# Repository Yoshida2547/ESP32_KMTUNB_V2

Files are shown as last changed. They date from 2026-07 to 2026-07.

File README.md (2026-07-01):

# ESP32KMUTNB_V2.0

A comprehensive ESP32-based embedded system design featuring multiple sensors, display interfaces, and USB connectivity for IoT and wearable applications.

## Overview

This project is a hardware design for an ESP32 microcontroller-based system that integrates:
- **Microcontroller**: ESP32 with USB-to-UART bridge
- **Sensors**: ADXL345 accelerometer, MAX30102 heart rate sensor, LPS22H barometric pressure sensor, HDC1080 humidity/temperature sensor
- **Display Interfaces**: TFT LCD display (3.5" 480×320 SPI) and I²C LCD module
- **Connectivity**: USB Type-C for programming and power, I²C and SPI communication buses
- **I/O**: Push buttons, RGB LED, buzzer, and GPIO headers

## Project Structure

```
ESP32KMUTNB_V2.0/
├── ESP32KMUTNB_V2.0.kicad_pro          # KiCad project file
├── ESP32KMUTNB_V2.0.kicad_sch          # Main schematic
├── ESP32KMUTNB_V2.0.kicad_pcb          # PCB layout
├── Microcontroller.kicad_sch           # Microcontroller subsystem
├── Sensor.kicad_sch                    # Sensor subsystem
├── TFT_Display.kicad_sch               # TFT display connections
├── LCD_Display.kicad_sch               # LCD display connections
├── Header.kicad_sch                    # GPIO header configuration
├── USB-to-UART Bridge.kicad_sch        # USB communication module
├── Bottons.kicad_sch                   # Button configuration
├── hardware_libs/                      # Custom libraries
│   ├── ADXL345BCCZ-RL.kicad_sym       # ADXL345 symbol
│   ├── MAX30102_Module.kicad_sym      # MAX30102 symbol
│   ├── TFT_LCD_Display.kicad_sym      # Display symbol
│   ├── footprints.pretty/             # Custom footprints
│   └── 3d_model/                      # 3D models for components
└── fp-lib-table                        # Footprint library table
```

## Key Components

| Component | Part Number | Function |
|---|---|---|
| Microcontroller | ESP32-S3 | Main processing unit |
| USB Bridge | CH340/CH341 | USB-to-UART conversion |
| Accelerometer | ADXL345BCCZ-RL | 3-axis acceleration sensing |
| Heart Rate Sensor | MAX30102 | PPG heart rate and SpO₂ measurement |
| Pressure Sensor | LPS22H | Barometric pressure and altitude |
| Humidity/Temp | HDC1080 | Temperature and humidity measurement |
| Display | ILI9488 | 3.5" TFT LCD interface |
| LED Indicators | WS2812B | RGB addressable LED |

## Schematic Organization

The design is organized into functional subsystems:

1. **Microcontroller** - ESP32 core with reset, boot circuitry, and power management
2. **USB Bridge** - CH340 UART-to-USB converter with ESD protection
3. **Sensors** - I²C sensor array with pull-up resistors and decoupling capacitors
4. **Display** - SPI TFT display interface with control signals
5. **Headers** - GPIO breakout connectors for expansion
6. **Power** - +5V input, +3.3V regulation with decoupling

## Pin Configuration

### I²C Sensors (I2C0/I2C1)
- SENSOR_SDA / SENSOR_SCL
- Connected to: ADXL345, MAX30102, LPS22H, HDC1080

### SPI Displays
- TFT LCD uses standard SPI interface
- CLK, MOSI, CS, DC, RESET signals

### GPIO Headers (J5)
- 32-pin connector with labeled I/O signals
- Supports additional peripherals and debugging

## Manufacturing Notes

- **PCB Layers**: 4-layer board
- **Design Date**: May 30, 2026
- **Revision**: A
- **3D Models**: Available for ADXL345 and MSP3520 components

## Design Files

- **KiCad Version**: 8.0.3 or later
- **Library Dependencies**: Custom symbols and footprints included
- **DXF Files**: MAX30102 module reference drawing included

## Usage

1. Open `ESP32KMUTNB_V2.0.kicad_pro` in KiCad
2. Review subsystem schematics for specific circuit details
3. Edit PCB layout in `ESP32KMUTNB_V2.0.kicad_pcb`
4. Generate production files (Gerbers, drill files) as needed

## Documentation

Refer to the individual schematic sheets for detailed circuit descriptions:
- Microcontroller configuration and boot circuitry
- Sensor connectivity and addressing
- Display interface pinout
- Power distribution and grounding strategy

## Author

Design by Surasak M. (Mark)
KMTUNB

## License

[Specify your license here]

## Contact

For questions or modifications, please contact the design team.

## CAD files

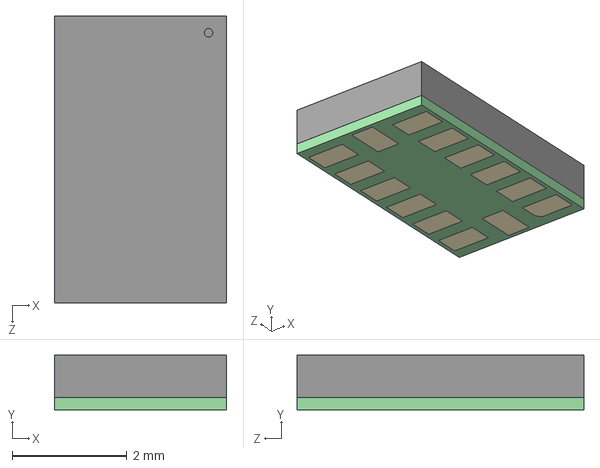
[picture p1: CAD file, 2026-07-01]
ADXL345BCCZ-RL.stp
3.00 x 0.95 x 5.00 mm

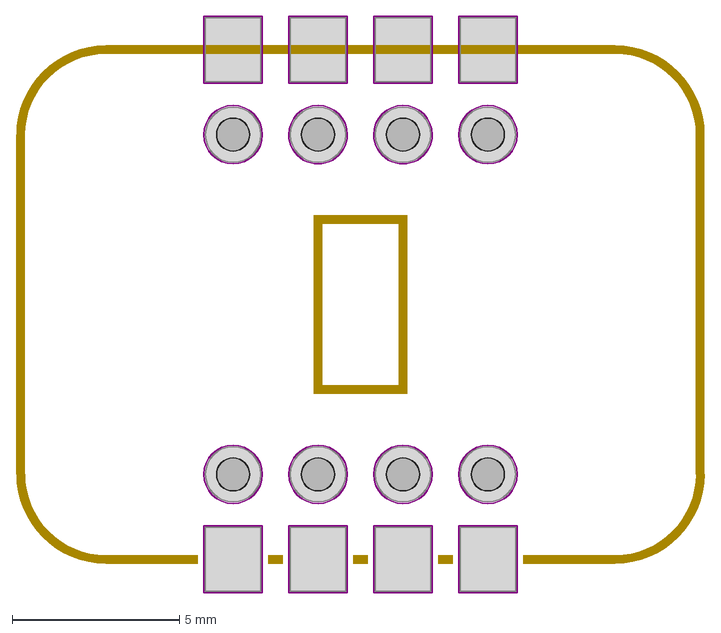
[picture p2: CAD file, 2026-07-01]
DXF_MAX30102_2026-07-01_AutoCAD2007.dxf
20.6 x 17.2 mm

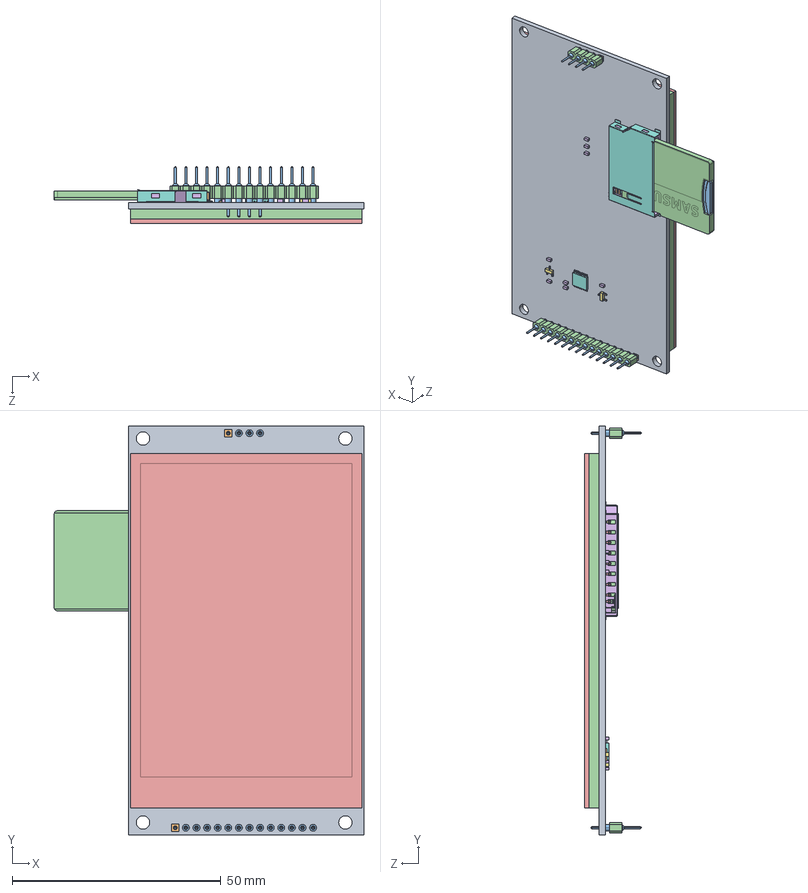
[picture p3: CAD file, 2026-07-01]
hardware_libs/3d_model/MSP3520.STEP
74.2 x 98.0 x 13.6 mm
TFT SPI Serial LCD Module 480X320 Driver IC ILI9488_XPT2046_MSP3520
card sd_Valor predeterminado
microSDCard
contact01.step
contact02.step
contact03.step
contact04.step
contact05.step
contact06.step
contact07.step
contact08.step
frame.step
contact09.step
cover.step
contact11.step
contact10.step
Штыревой разъем 14 конт шаг 2.54мм
Штыревой разъем 4 конт шаг 2.54мм

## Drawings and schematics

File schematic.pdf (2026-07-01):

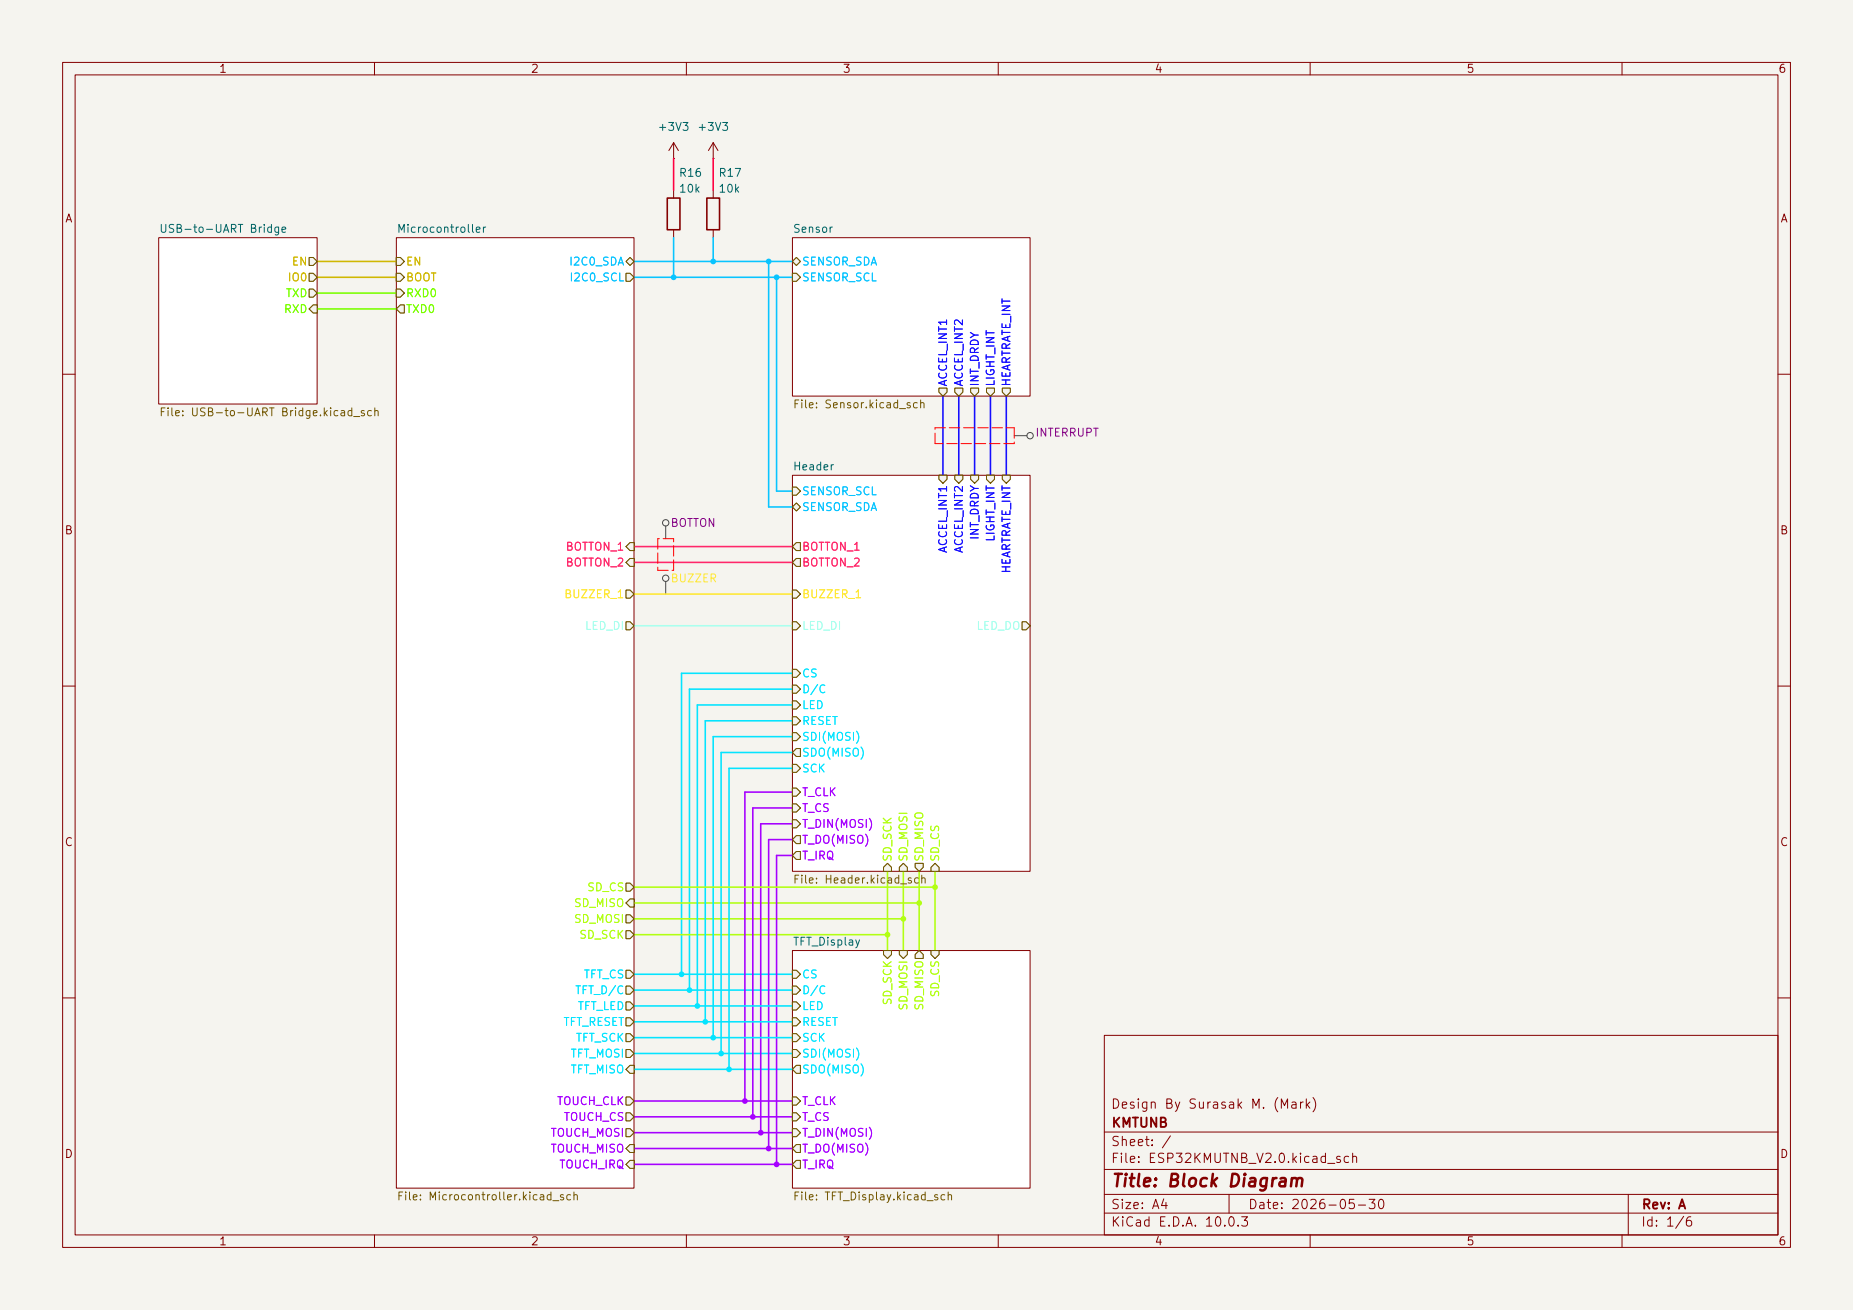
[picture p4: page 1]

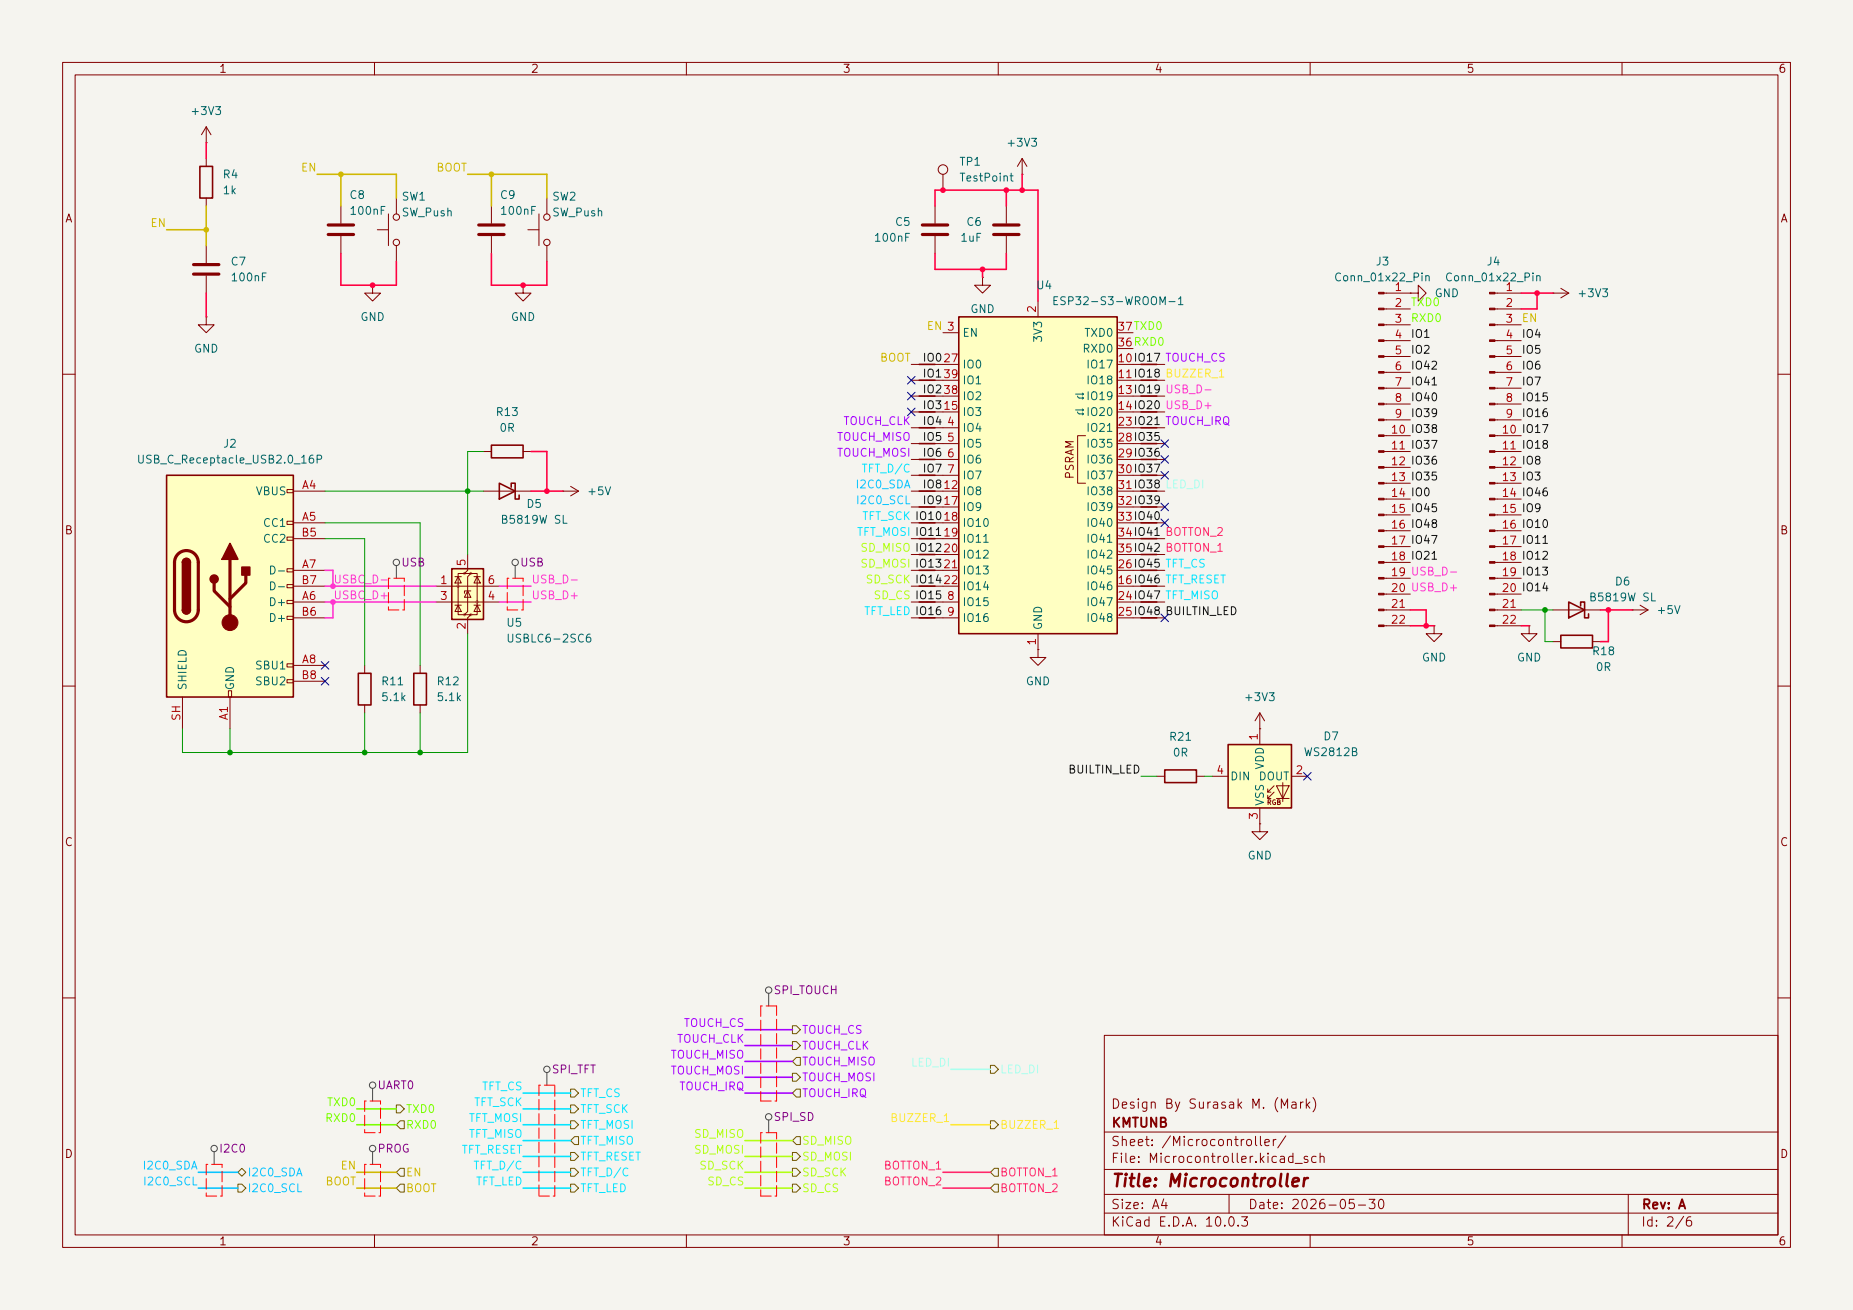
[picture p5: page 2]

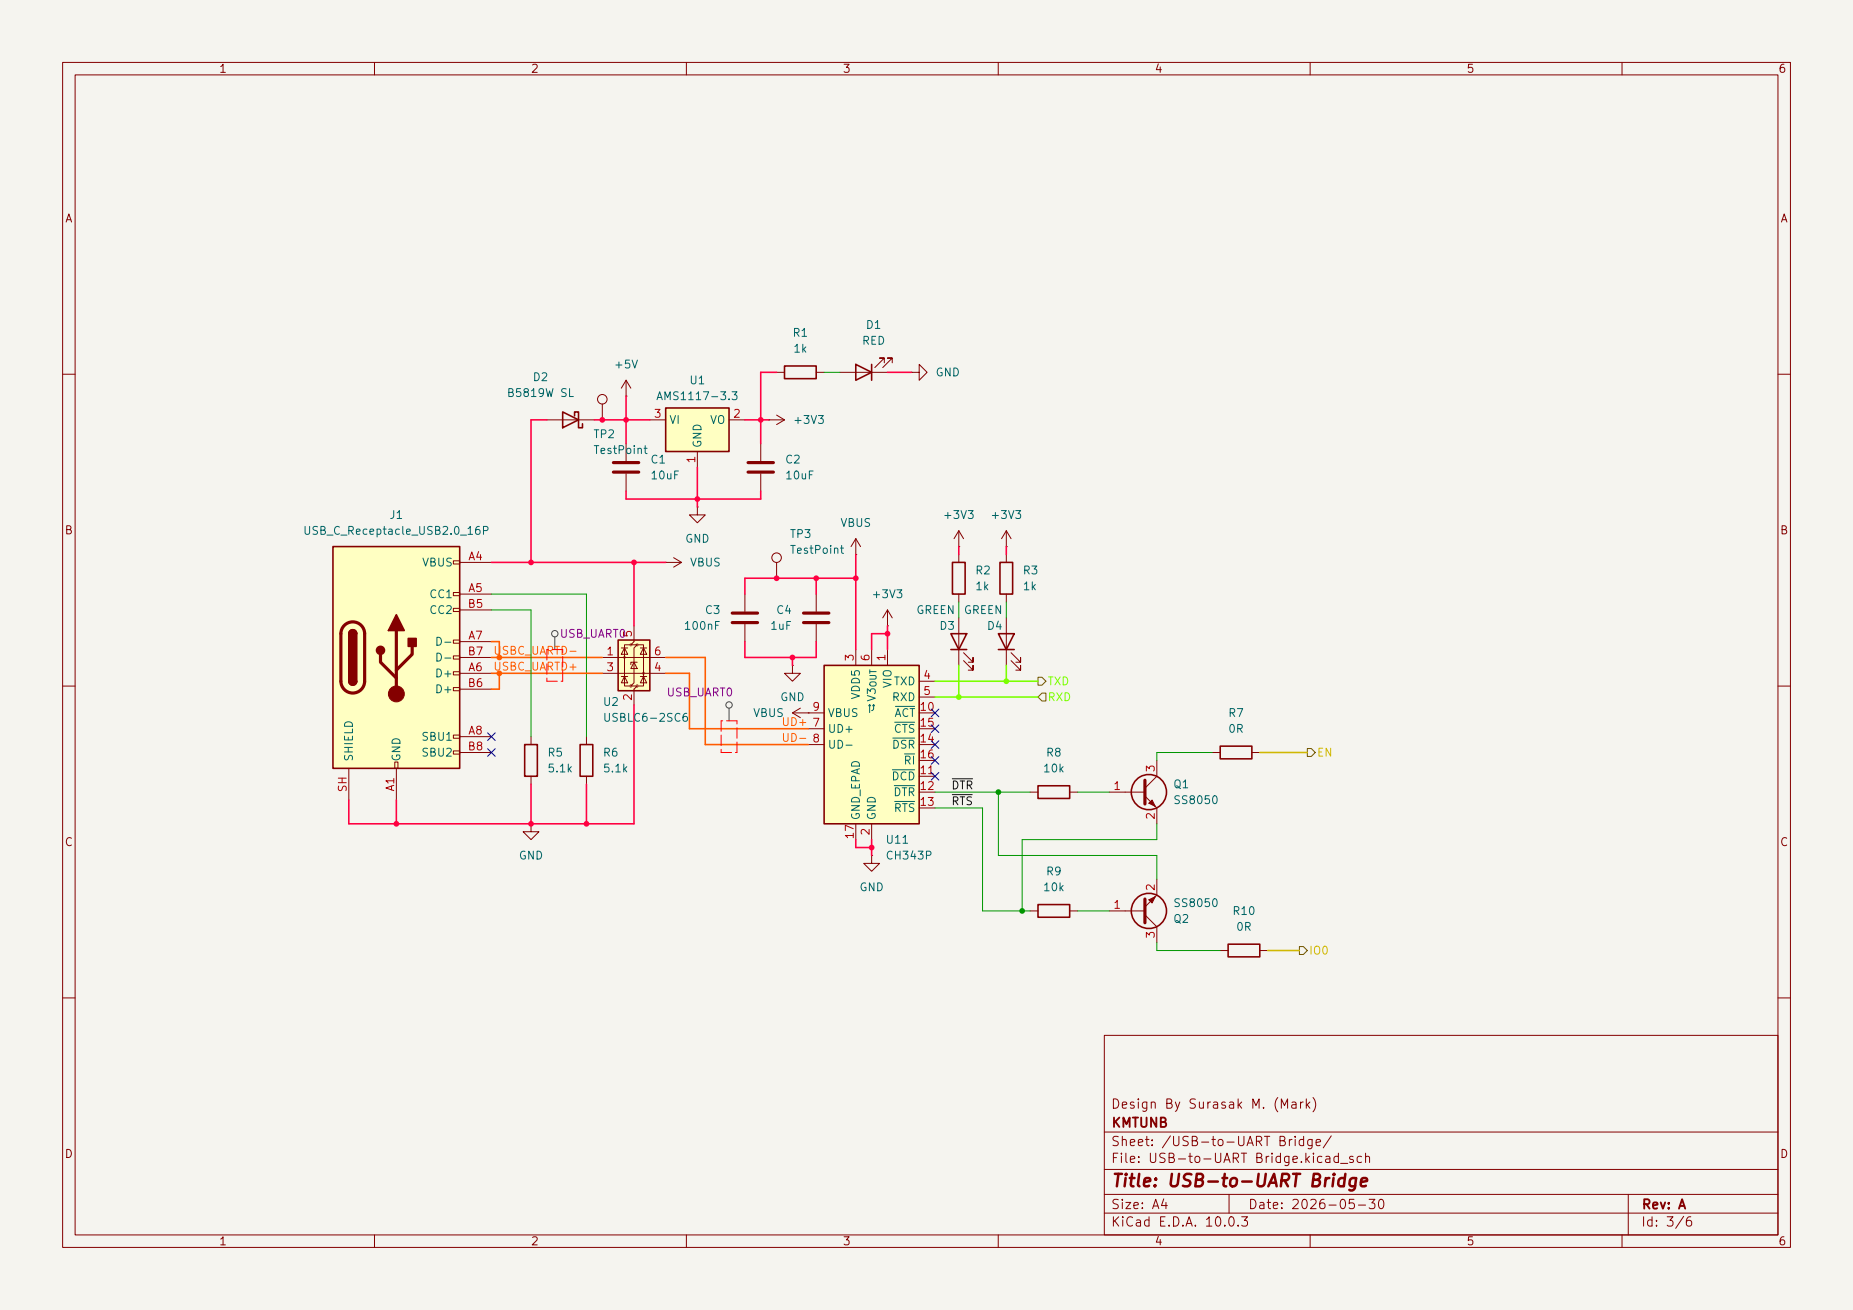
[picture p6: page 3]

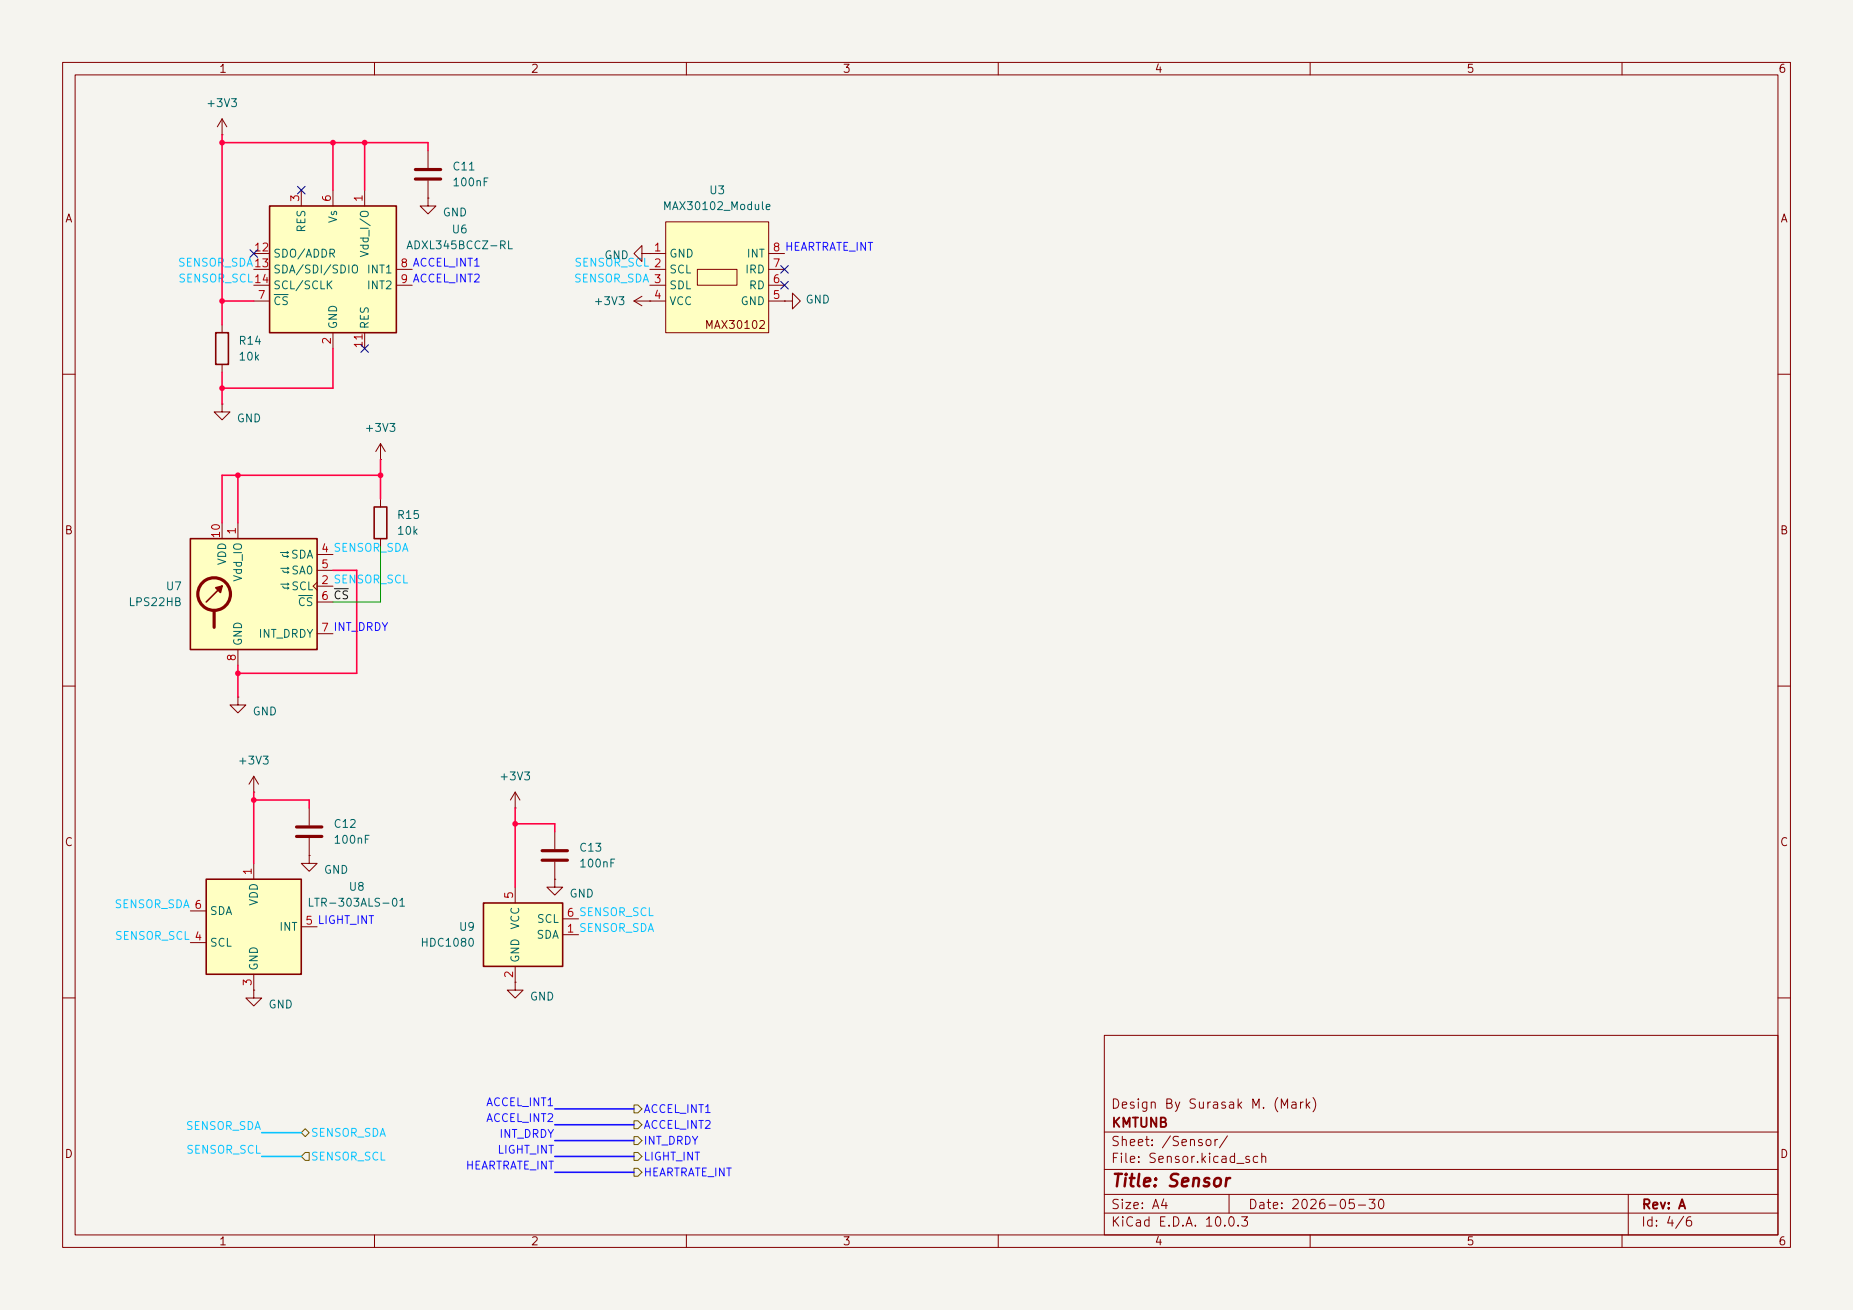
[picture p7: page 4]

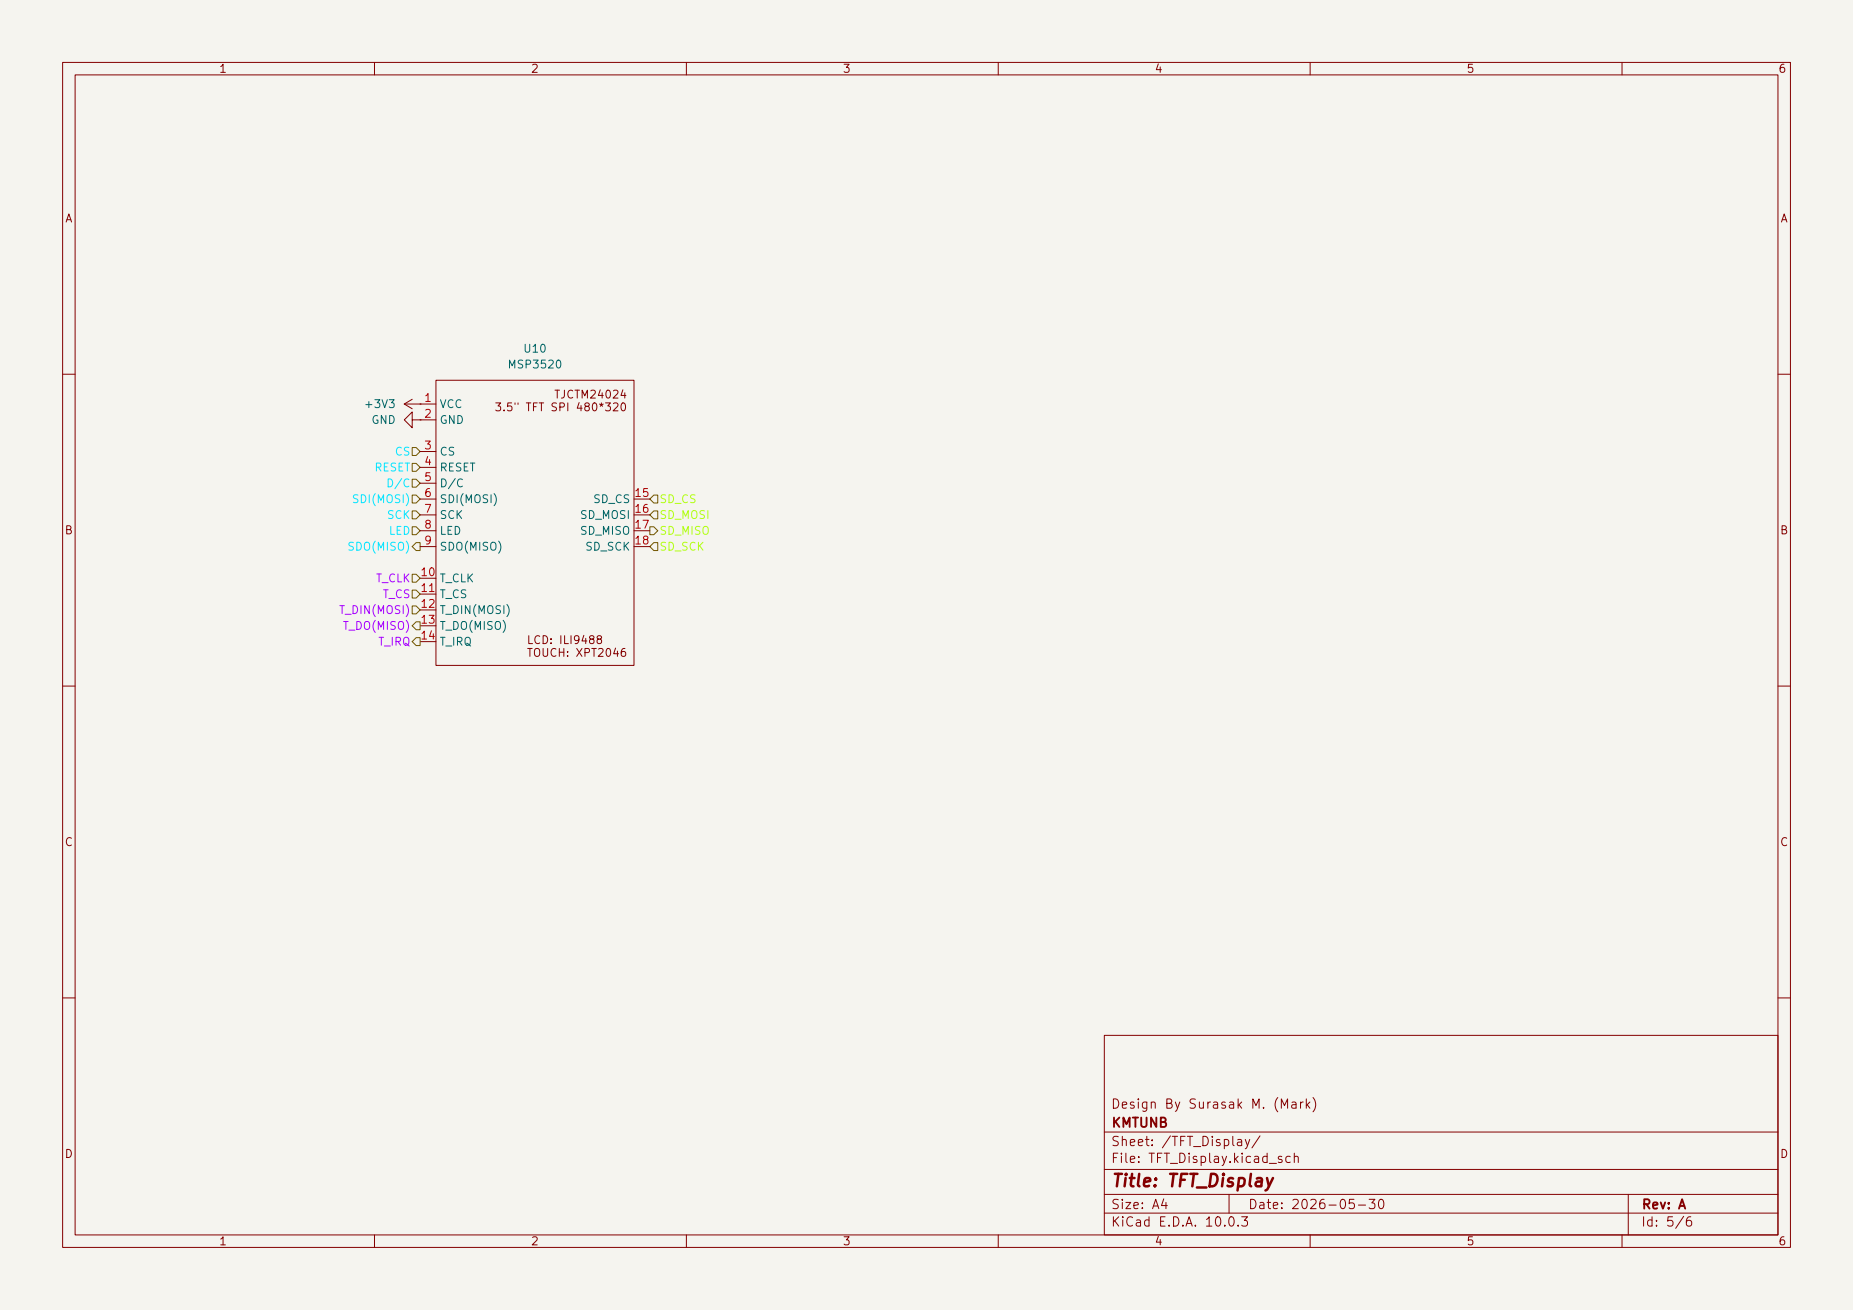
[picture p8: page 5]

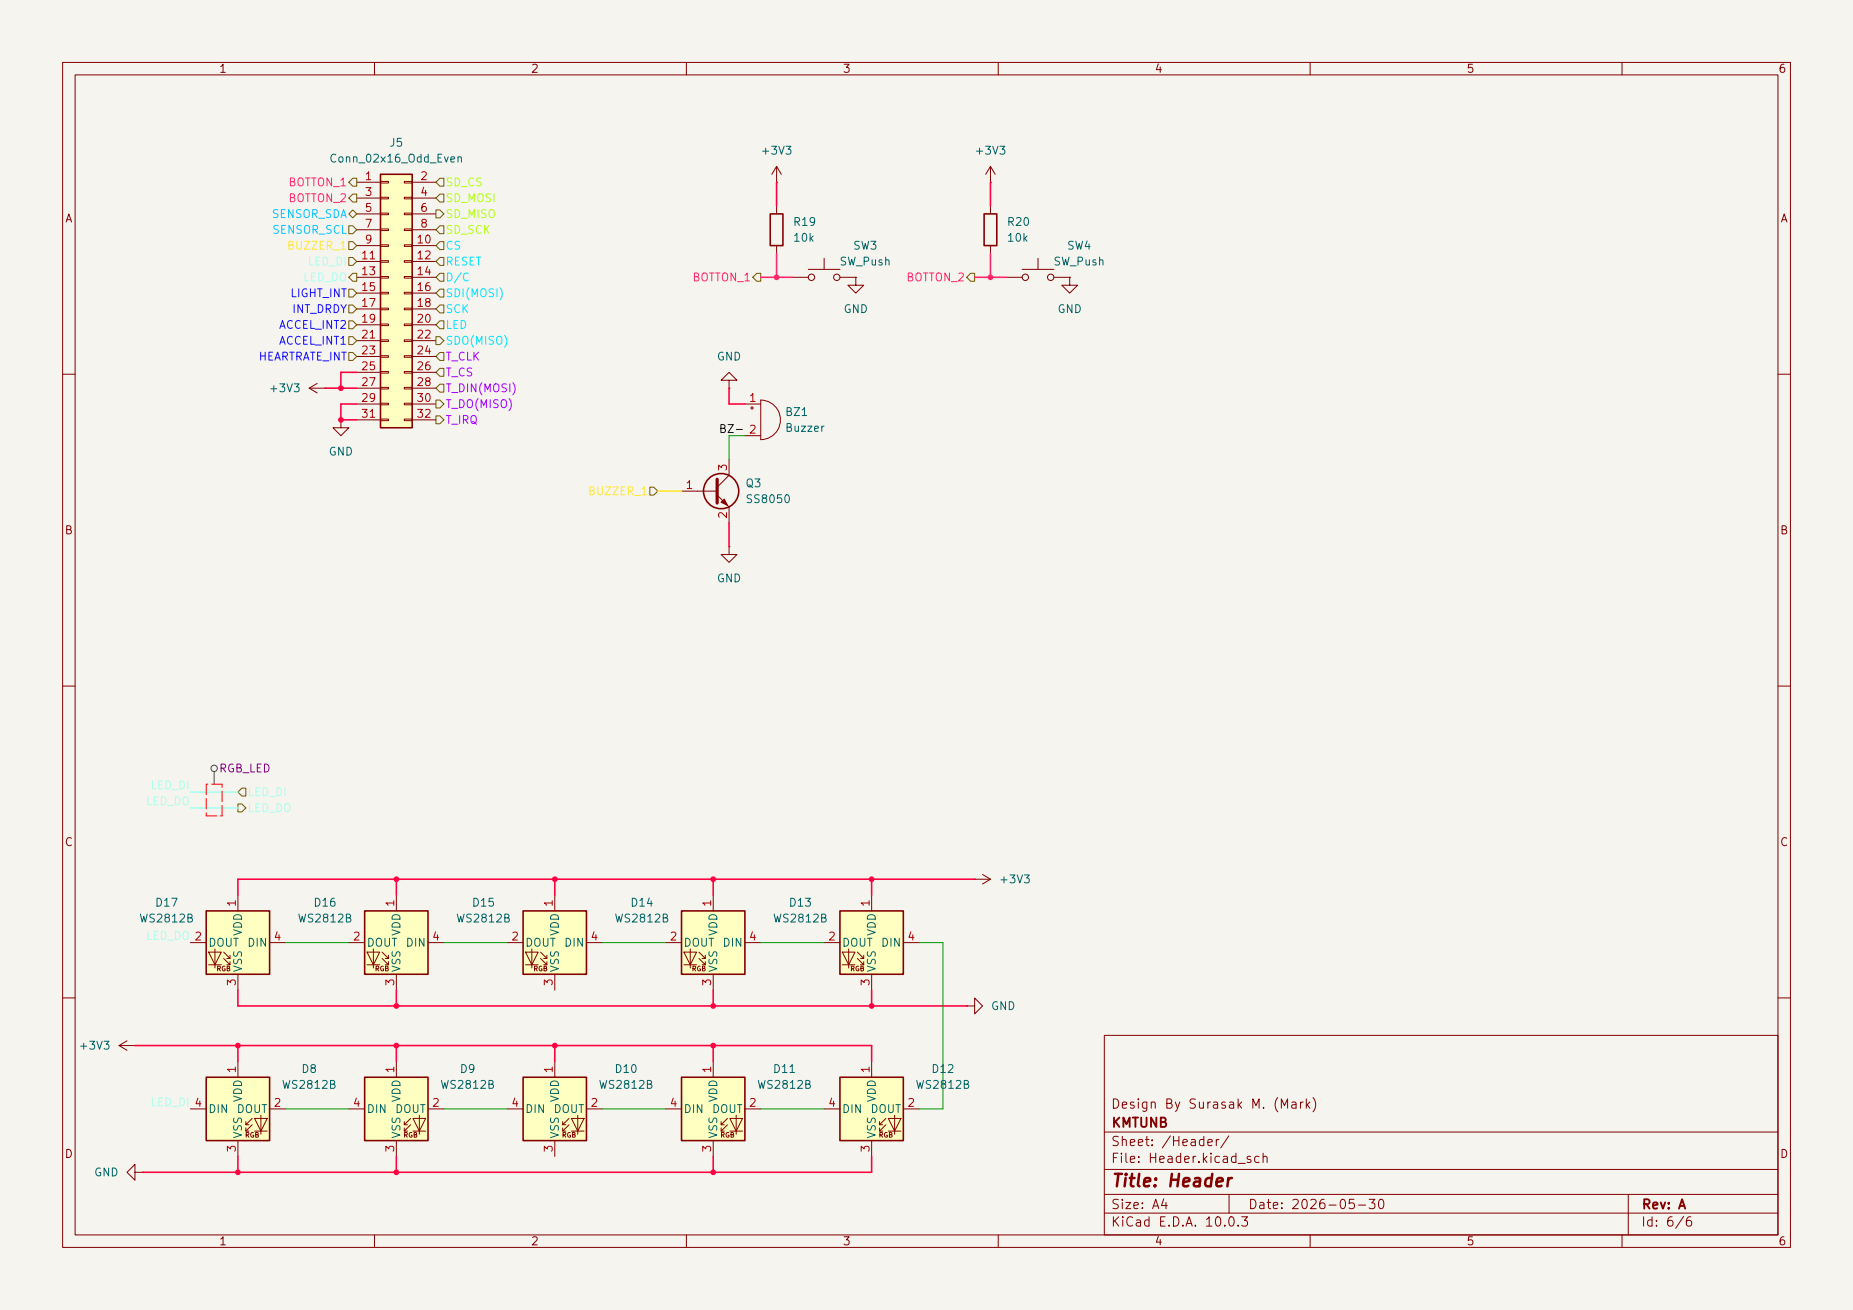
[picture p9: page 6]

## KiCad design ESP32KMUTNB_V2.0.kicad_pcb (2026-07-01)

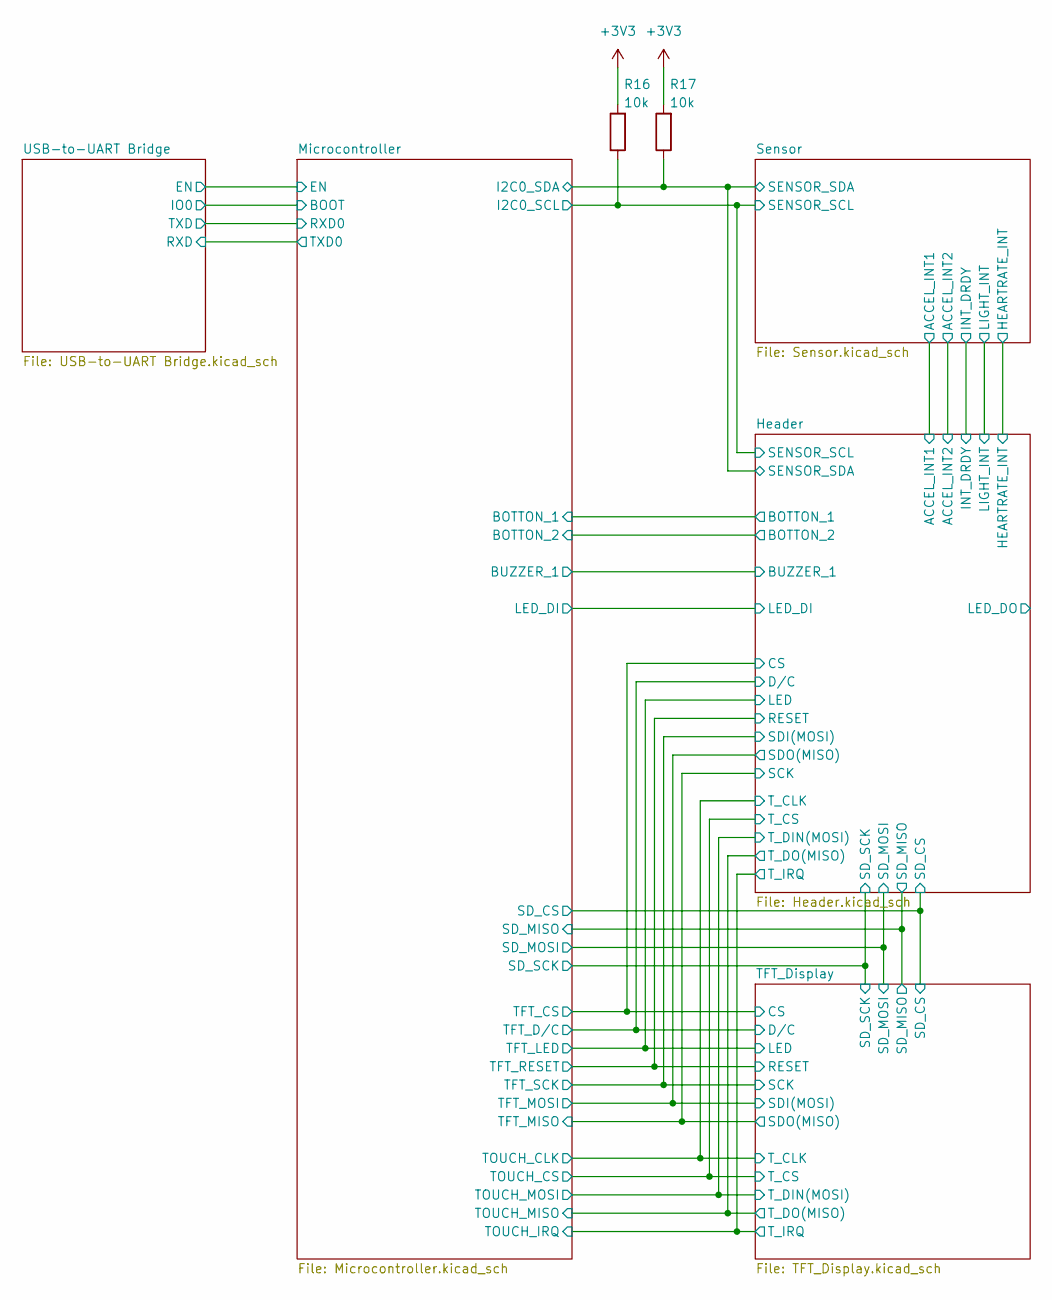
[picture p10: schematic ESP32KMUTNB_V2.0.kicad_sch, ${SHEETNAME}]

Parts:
R16, R17: 10k; R_0603_1608Metric_Pad0.98x0.95mm_HandSolder; MPN 0603WAF1002T5E

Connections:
+3V3: R16.2, R17.2; also elsewhere on the board
/Microcontroller/I2C0_SCL: R16.1; also elsewhere on the board
/Microcontroller/I2C0_SDA: R17.1; also elsewhere on the board

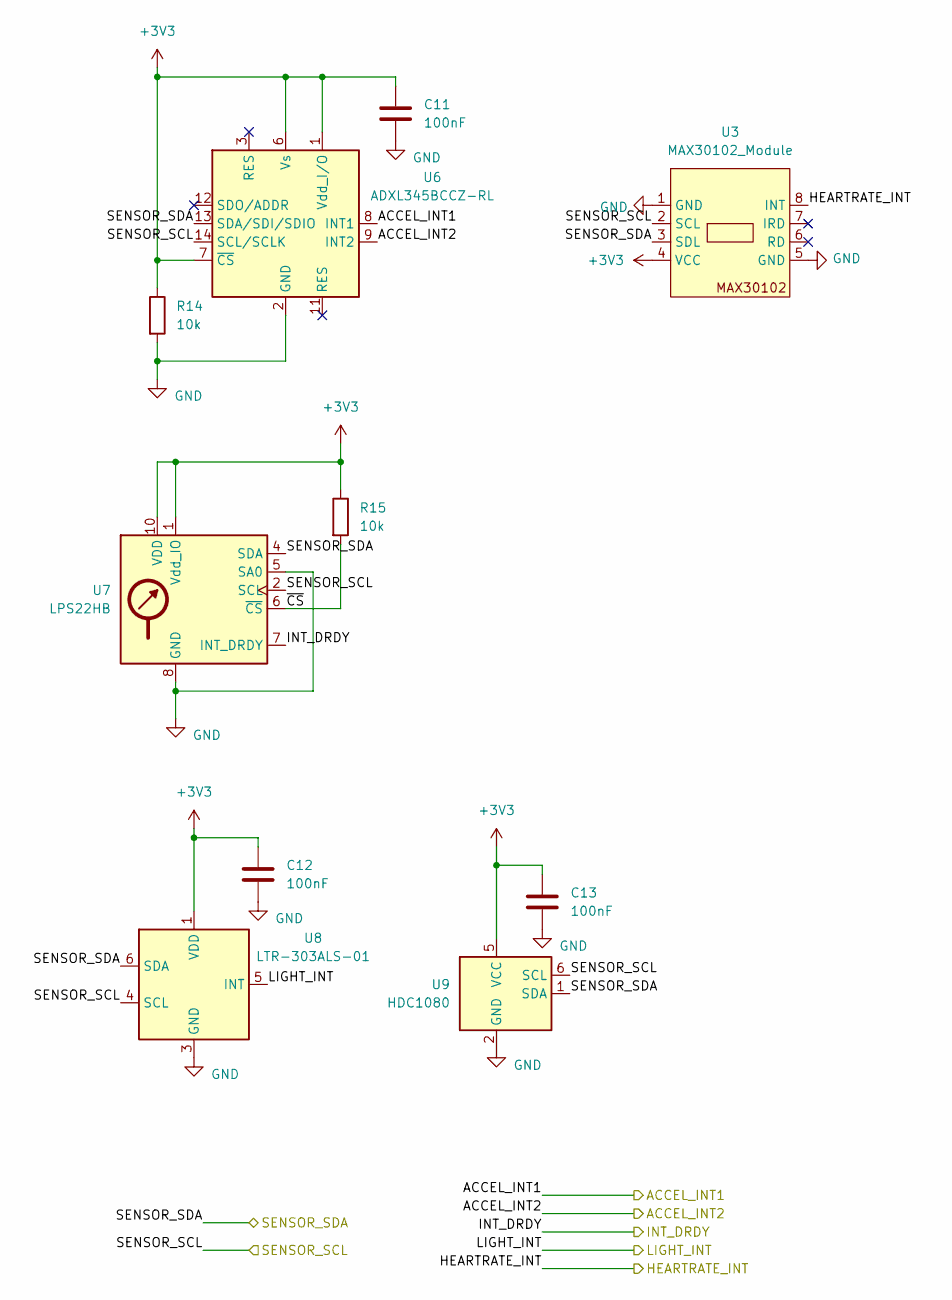
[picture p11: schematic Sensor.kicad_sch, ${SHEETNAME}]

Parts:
C11, C12, C13: 100nF; C_0402_1005Metric_Pad0.74x0.62mm_HandSolder; MPN CL05B104KO5NNNC
R14, R15: 10k; R_0603_1608Metric_Pad0.98x0.95mm_HandSolder; MPN 0603WAF1002T5E
U3: MAX30102_Module; MAX30102
U6: ADXL345BCCZ-RL; LGA-14_3x5mm_P0.8mm_LayoutBorder1x6y; MPN ADXL345BCCZ-RL
U7: LPS22HB; ST_HLGA-10_2x2mm_P0.5mm_LayoutBorder3x2y; MPN LPS22HBTR
U8: LTR-303ALS-01; Lite-On_LTR-303ALS-01; MPN LTR-303ALS-01
U9: HDC1080; Texas_PWSON-N6; MPN HDC1080DMBR

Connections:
+3V3: C11.1, C12.1, C13.1, R14.1, R15.1, U3.4 (VCC), U6.1 (Vdd_I/O), U6.6 (Vs), U6.7 (~CS), U7.1 (Vdd_IO), U7.10 (VDD), U8.1 (VDD), U9.5 (VCC); also elsewhere on the board
/Microcontroller/I2C0_SCL: U3.2 (SCL), U6.14 (SCL/SCLK), U7.2 (SCL), U8.4 (SCL), U9.6 (SCL); also elsewhere on the board
/Microcontroller/I2C0_SDA: U3.3 (SDL), U6.13 (SDA/SDI/SDIO), U7.4 (SDA), U8.6 (SDA), U9.1 (SDA); also elsewhere on the board
/Sensor/ACCEL_INT1: U6.8 (INT1); also elsewhere on the board
/Sensor/ACCEL_INT2: U6.9 (INT2); also elsewhere on the board
/Sensor/HEARTRATE_INT: U3.8 (INT); also elsewhere on the board
/Sensor/INT_DRDY: U7.7 (INT_DRDY); also elsewhere on the board
/Sensor/LIGHT_INT: U8.5 (INT); also elsewhere on the board
/Sensor/~CS: R15.2, U7.6 (~CS)
GND: C11.2, C12.2, C13.2, R14.2, U3.1 (GND), U3.5 (GND), U6.2 (GND), U6.4 (GND), U6.5 (GND), U7.3 (GND), U7.5 (SA0), U7.8 (GND), U7.9 (GND), U8.3 (GND), U9.2 (GND); also elsewhere on the board

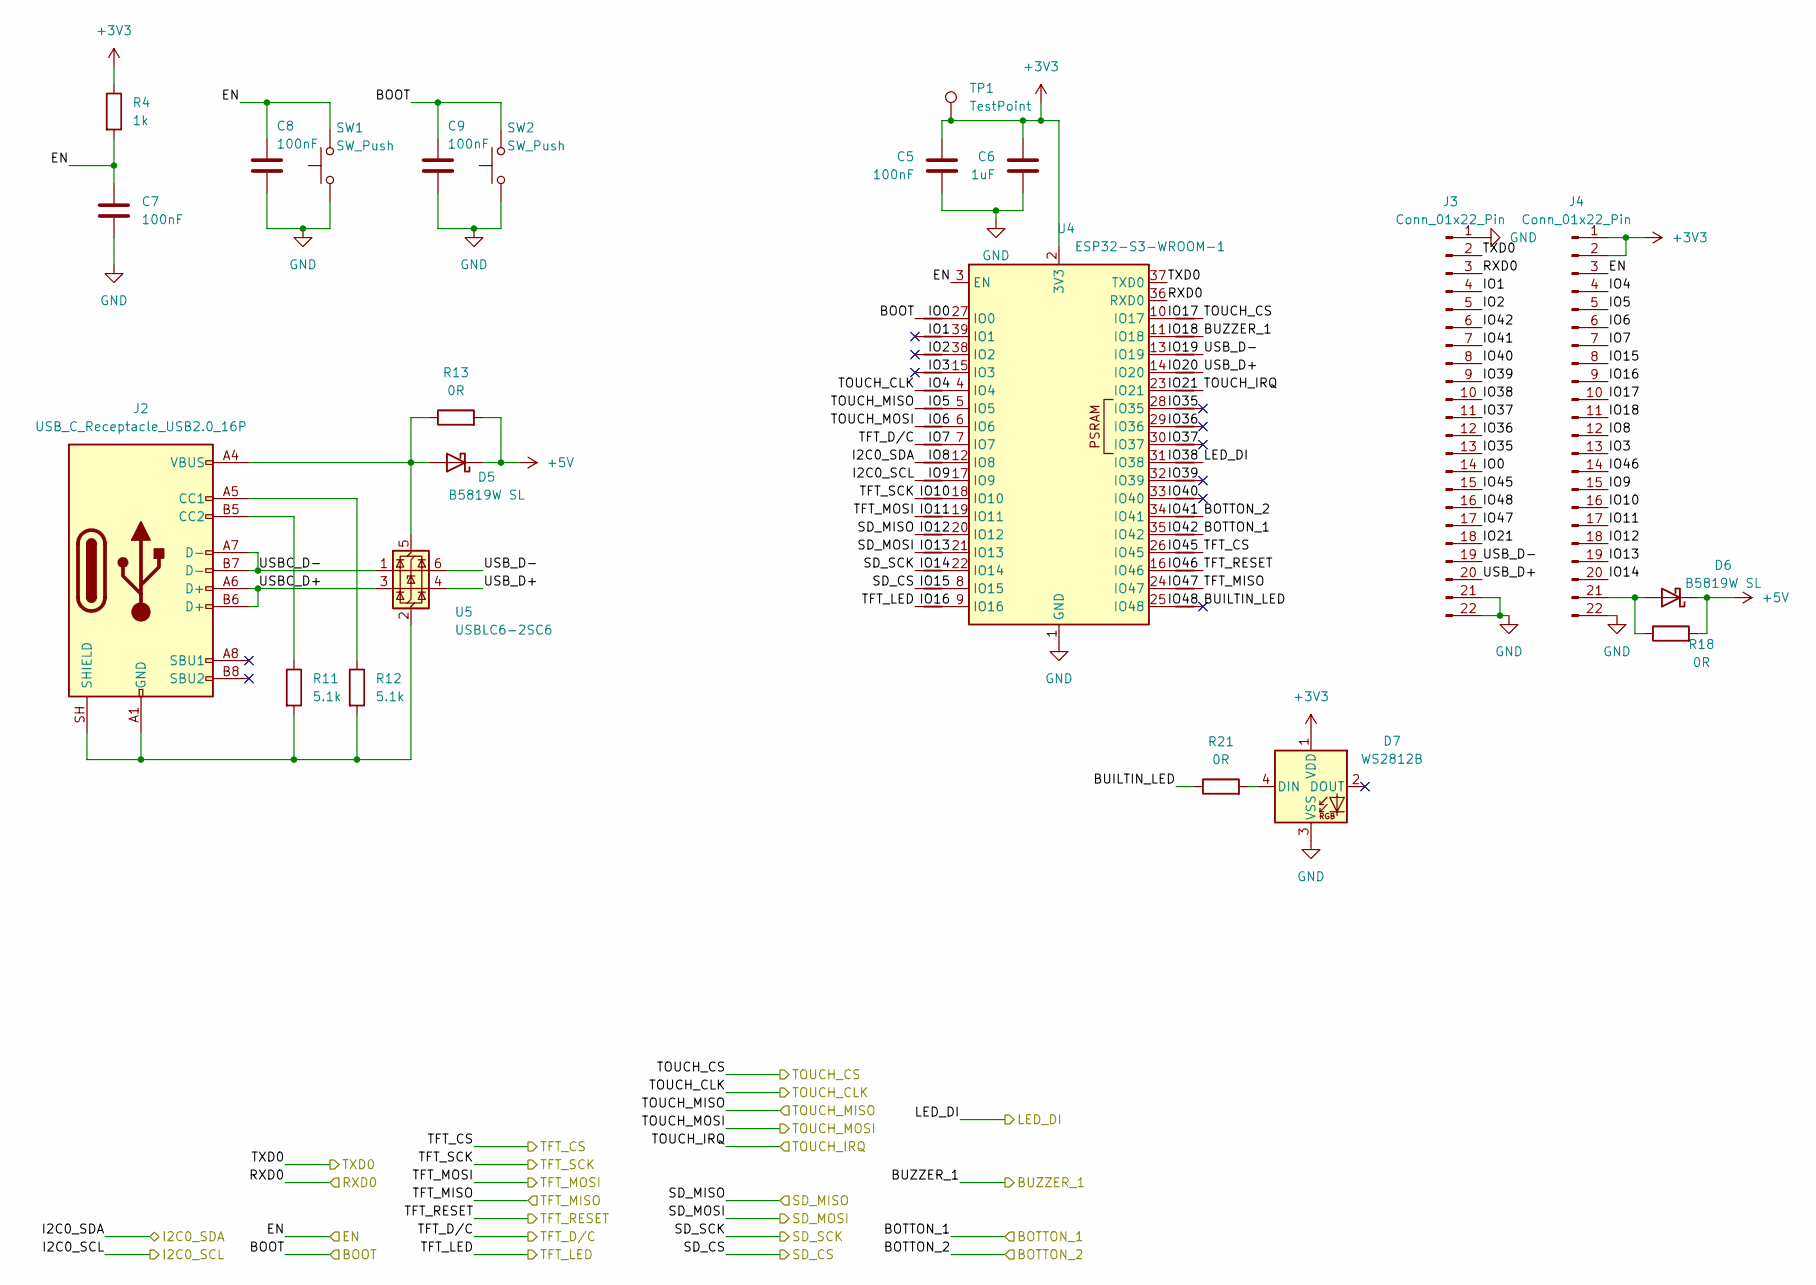
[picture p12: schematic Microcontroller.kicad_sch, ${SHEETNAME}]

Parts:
C5, C7, C8, C9: 100nF; C_0402_1005Metric_Pad0.74x0.62mm_HandSolder; MPN CL05B104KO5NNNC
C6: 1uF; C_0603_1608Metric_Pad1.08x0.95mm_HandSolder; MPN CL10A105KB8NNNC
D5, D6: B5819W SL; D_SOD-123; MPN B5819W SL
D7: WS2812B; LED_WS2812B_PLCC4_5.0x5.0mm_P3.2mm
J2: USB_C_Receptacle_USB2.0_16P; USB_C_Receptacle_G-Switch_GT-USB-7010ASV; MPN G-Switch GT-USB-7010ASV
J3, J4: Conn_01x22_Pin; PinSocket_1x22_P2.54mm_Vertical
NT1, NT2, NT3, NT4, NT5, NT6, NT7, NT8, NT9, NT10, NT11, NT12, NT13, NT14, NT15, NT16, NT17, NT18, NT19, NT20, NT21, NT22, NT23, NT24, NT25, NT26, NT27, NT28, NT29, NT30, NT31, NT32, NT33, NT34: NetTie_2; NetTie-2_SMD_Pad0.5mm
R4: 1k; R_0603_1608Metric_Pad0.98x0.95mm_HandSolder; MPN 0603WAF1001T5E
R11, R12: 5.1k; R_0603_1608Metric_Pad0.98x0.95mm_HandSolder; MPN 0603WAF5101T5E
R13, R18, R21: 0R; R_0603_1608Metric_Pad0.98x0.95mm_HandSolder; MPN 0603WAF0000T5E
SW1, SW2: SW_Push; SW_SPST_B3U-1000P; MPN XUNPU TS-1088-AR02016
TP1: TestPoint; TestPoint_Pad_D1.5mm
U4: ESP32-S3-WROOM-1; MPN ESP32-S3-WROOM-1-N8R2
U5: USBLC6-2SC6; SOT-23-6; MPN USBLC6-2SC6

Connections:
+3V3: C5.1, C6.1, D7.1 (VDD), J4.1, J4.2, R4.1, TP1.1 (1_1), U4.2 (3V3); also elsewhere on the board
+5V: D5.1 (K), D6.1 (K), R13.2, R18.2; also elsewhere on the board
/Header/LED_DI: NT22.2; also elsewhere on the board
/Microcontroller/BOOT: C9.1, NT14.1, SW2.2; also elsewhere on the board
/Microcontroller/BOTTON_1: NT27.2; also elsewhere on the board
/Microcontroller/BOTTON_2: NT25.2; also elsewhere on the board
/Microcontroller/BUILTIN_LED: NT32.2, R21.1
/Microcontroller/BUZZER_1: NT28.2; also elsewhere on the board
/Microcontroller/EN: C7.1, C8.1, J4.3, R4.2, SW1.2, U4.3 (EN); also elsewhere on the board
/Microcontroller/I2C0_SCL: NT6.1; also elsewhere on the board
/Microcontroller/I2C0_SDA: NT5.1; also elsewhere on the board
/Microcontroller/IO0: J3.14, NT14.2, U4.27 (IO0)
/Microcontroller/IO1: J3.4, NT15.2 (2_2), U4.39 (IO1)
/Microcontroller/IO2: J3.5, NT16.2 (2_2), U4.38 (IO2)
/Microcontroller/IO3: J4.13, NT17.2 (2_2), U4.15 (IO3)
/Microcontroller/IO4: J4.4, NT1.2, U4.4 (IO4)
/Microcontroller/IO5: J4.5, NT2.2, U4.5 (IO5)
/Microcontroller/IO6: J4.6, NT3.2, U4.6 (IO6)
/Microcontroller/IO7: J4.7, NT4.2, U4.7 (IO7)
/Microcontroller/IO8: J4.12, NT5.2, U4.12 (IO8)
/Microcontroller/IO9: J4.15, NT6.2, U4.17 (IO9)
/Microcontroller/IO10: J4.16, NT7.2, U4.18 (IO10)
/Microcontroller/IO11: J4.17, NT8.2, U4.19 (IO11)
/Microcontroller/IO12: J4.18, NT9.2, U4.20 (IO12)
/Microcontroller/IO13: J4.19, NT10.2, U4.21 (IO13)
/Microcontroller/IO14: J4.20, NT11.2, U4.22 (IO14)
/Microcontroller/IO15: J4.8, NT12.2, U4.8 (IO15)
/Microcontroller/IO16: J4.9, NT13.2, U4.9 (IO16)
/Microcontroller/IO17: J4.10, NT26.1, U4.10 (IO17)
/Microcontroller/IO18: J4.11, NT28.1, U4.11 (IO18)
/Microcontroller/IO19: NT33.1, U4.13 (IO19)
/Microcontroller/IO20: NT34.1, U4.14 (IO20)
/Microcontroller/IO21: J3.18, NT18.1, U4.23 (IO21)
/Microcontroller/IO35: J3.13, NT19.1 (1_1), U4.28 (IO35)
/Microcontroller/IO36: J3.12, NT20.1 (1_1), U4.29 (IO36)
/Microcontroller/IO37: J3.11, NT21.1 (1_1), U4.30 (IO37)
/Microcontroller/IO38: J3.10, NT22.1, U4.31 (IO38)
/Microcontroller/IO39: J3.9, NT23.1 (1_1), U4.32 (IO39)
/Microcontroller/IO40: J3.8, NT24.1 (1_1), U4.33 (IO40)
/Microcontroller/IO41: J3.7, NT25.1, U4.34 (IO41)
/Microcontroller/IO42: J3.6, NT27.1, U4.35 (IO42)
/Microcontroller/IO45: J3.15, NT29.1, U4.26 (IO45)
/Microcontroller/IO46: J4.14, NT30.1, U4.16 (IO46)
/Microcontroller/IO47: J3.17, NT31.1, U4.24 (IO47)
/Microcontroller/IO48: J3.16, NT32.1, U4.25 (IO48)
/Microcontroller/RXD0: J3.3, U4.36 (RXD0); also elsewhere on the board
/Microcontroller/SD_CS: NT12.1; also elsewhere on the board
/Microcontroller/SD_MISO: NT9.1; also elsewhere on the board
/Microcontroller/SD_MOSI: NT10.1; also elsewhere on the board
/Microcontroller/SD_SCK: NT11.1; also elsewhere on the board
/Microcontroller/TFT_CS: NT29.2; also elsewhere on the board
/Microcontroller/TFT_D/C: NT4.1; also elsewhere on the board
/Microcontroller/TFT_LED: NT13.1; also elsewhere on the board
/Microcontroller/TFT_MISO: NT31.2; also elsewhere on the board
/Microcontroller/TFT_MOSI: NT8.1; also elsewhere on the board
/Microcontroller/TFT_RESET: NT30.2; also elsewhere on the board
/Microcontroller/TFT_SCK: NT7.1; also elsewhere on the board
/Microcontroller/TOUCH_CLK: NT1.1; also elsewhere on the board
/Microcontroller/TOUCH_CS: NT26.2; also elsewhere on the board
/Microcontroller/TOUCH_IRQ: NT18.2; also elsewhere on the board
/Microcontroller/TOUCH_MISO: NT2.1; also elsewhere on the board
/Microcontroller/TOUCH_MOSI: NT3.1; also elsewhere on the board
/Microcontroller/TXD0: J3.2, U4.37 (TXD0); also elsewhere on the board
/Microcontroller/USBC_D+: J2.A6 (D+), J2.B6 (D+), U5.3 (I/O2)
/Microcontroller/USBC_D-: J2.A7 (D-), J2.B7 (D-), U5.1 (I/O1)
/Microcontroller/USB_D+: J3.20, NT34.2, U5.4 (I/O2)
/Microcontroller/USB_D-: J3.19, NT33.2, U5.6 (I/O1)
GND: C5.2, C6.2, C7.2, C8.2, C9.2, D7.3 (VSS), J3.1, J3.21, J3.22, J4.22, SW1.1, SW2.1, U4.1 (GND), U4.40 (GND), U4.41 (GND); also elsewhere on the board
unnamed: D5.2 (A), J2.A4 (VBUS), J2.A9 (VBUS), J2.B4 (VBUS), J2.B9 (VBUS), R13.1, U5.5 (VBUS)
unnamed: D6.2 (A), J4.21, R18.1
unnamed: D7.4 (DIN), R21.2
unnamed: J2.A5 (CC1), R12.1
unnamed: J2.B5 (CC2), R11.1
unnamed: J2.A1 (GND), J2.A12 (GND), J2.B1 (GND), J2.B12 (GND), J2.SH (SHIELD), R11.2, R12.2, U5.2 (GND)

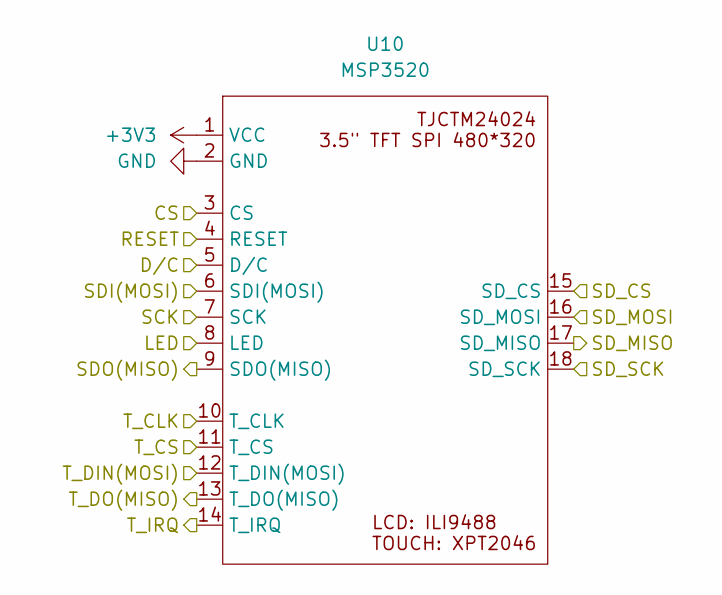
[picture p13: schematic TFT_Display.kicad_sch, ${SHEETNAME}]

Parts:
U10: MSP3520; MSP3520_WithoutHole

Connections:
+3V3: U10.1 (VCC); also elsewhere on the board
/Microcontroller/SD_CS: U10.15 (SD_CS); also elsewhere on the board
/Microcontroller/SD_MISO: U10.17 (SD_MISO); also elsewhere on the board
/Microcontroller/SD_MOSI: U10.16 (SD_MOSI); also elsewhere on the board
/Microcontroller/SD_SCK: U10.18 (SD_SCK); also elsewhere on the board
/Microcontroller/TFT_CS: U10.3 (CS); also elsewhere on the board
/Microcontroller/TFT_D/C: U10.5 (D/C); also elsewhere on the board
/Microcontroller/TFT_LED: U10.8 (LED); also elsewhere on the board
/Microcontroller/TFT_MISO: U10.9 (SDO(MISO)); also elsewhere on the board
/Microcontroller/TFT_MOSI: U10.6 (SDI(MOSI)); also elsewhere on the board
/Microcontroller/TFT_RESET: U10.4 (RESET); also elsewhere on the board
/Microcontroller/TFT_SCK: U10.7 (SCK); also elsewhere on the board
/Microcontroller/TOUCH_CLK: U10.10 (T_CLK); also elsewhere on the board
/Microcontroller/TOUCH_CS: U10.11 (T_CS); also elsewhere on the board
/Microcontroller/TOUCH_IRQ: U10.14 (T_IRQ); also elsewhere on the board
/Microcontroller/TOUCH_MISO: U10.13 (T_DO(MISO)); also elsewhere on the board
/Microcontroller/TOUCH_MOSI: U10.12 (T_DIN(MOSI)); also elsewhere on the board
GND: U10.2 (GND); also elsewhere on the board

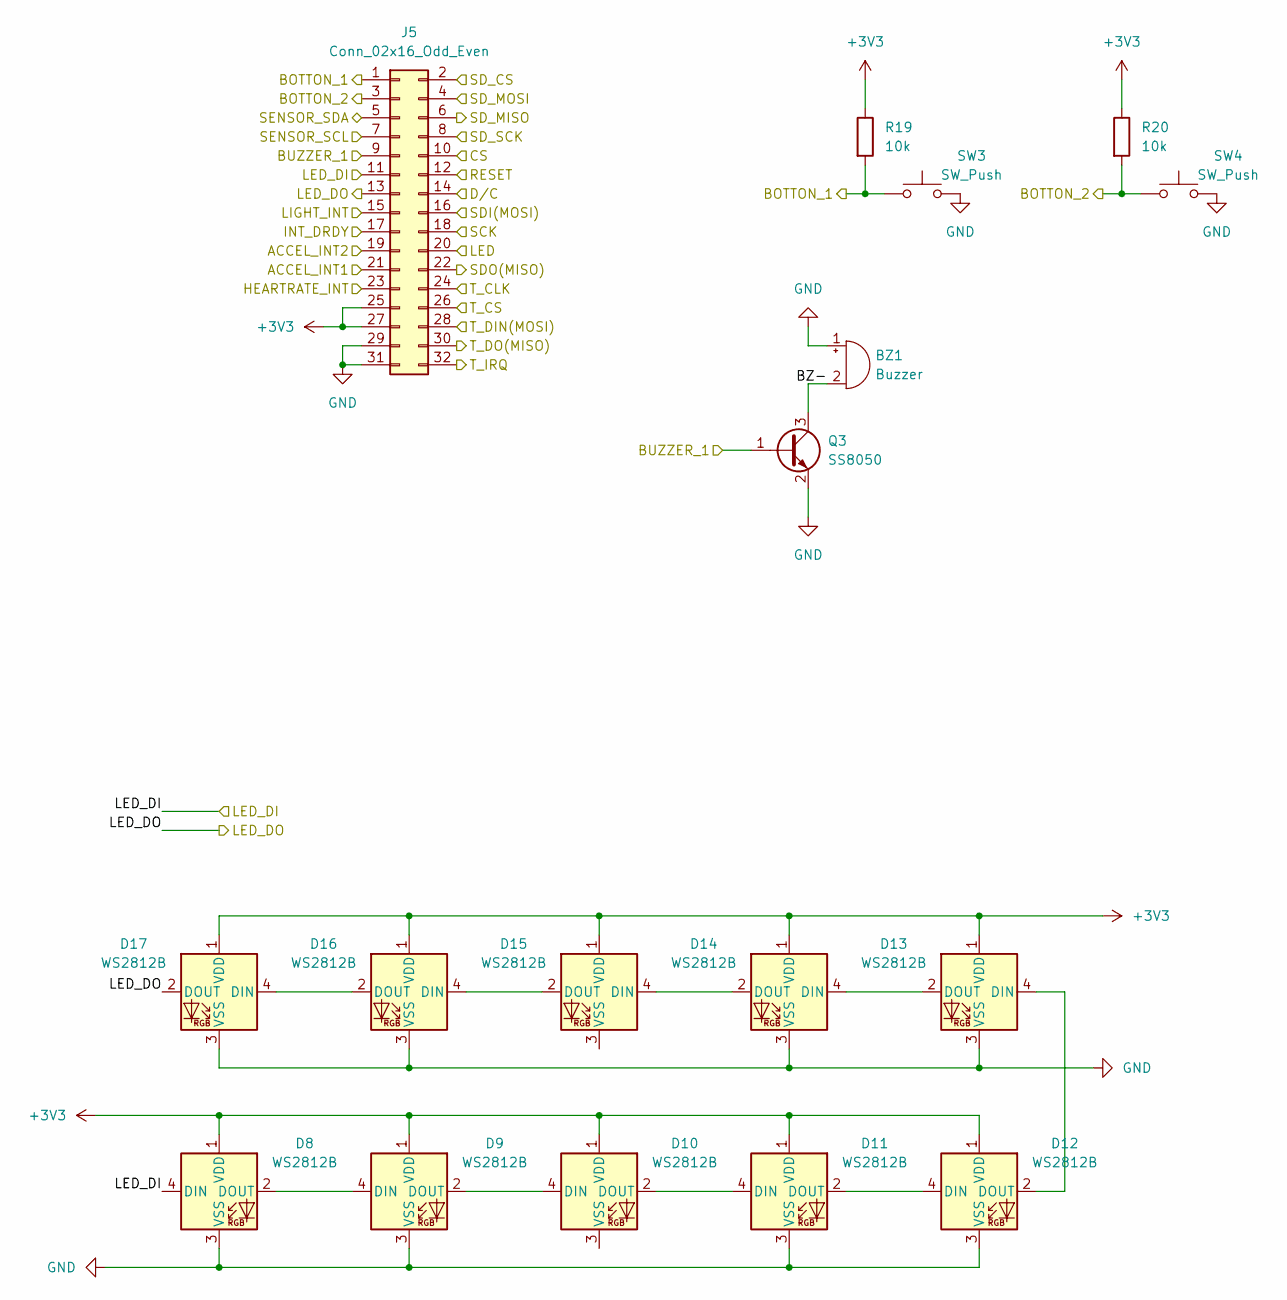
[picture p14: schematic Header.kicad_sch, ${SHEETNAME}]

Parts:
BZ1: Buzzer; Huaneng MLT-9650; MPN MLT-9650
D8, D9, D10, D11, D12, D13, D14, D15, D16, D17: WS2812B; LED_WS2812B_PLCC4_5.0x5.0mm_P3.2mm
J5: Conn_02x16_Odd_Even; PinHeader_2x16_P2.54mm_Vertical
Q3: SS8050; SOT-23; MPN S8050 J3Y(RANGE:200-350)
R19, R20: 10k; R_0603_1608Metric_Pad0.98x0.95mm_HandSolder; MPN 0603WAF1002T5E
SW3, SW4: SW_Push; SW_Push_1TS009xxxx-xxxx-xxxx_6x6x5mm; MPN 1TS009A-1800-5000-CT

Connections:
+3V3: D8.1 (VDD), D9.1 (VDD), D10.1 (VDD), D11.1 (VDD), D12.1 (VDD), D13.1 (VDD), D14.1 (VDD), D15.1 (VDD), D16.1 (VDD), D17.1 (VDD), J5.25, J5.27, R19.1, R20.1; also elsewhere on the board
/Header/BZ-: BZ1.2 (-), Q3.3 (C)
/Header/LED_DI: D8.4 (DIN), J5.11; also elsewhere on the board
/Header/LED_DO: D17.2 (DOUT), J5.13
/Microcontroller/BOTTON_1: J5.1, R19.2, SW3.1; also elsewhere on the board
/Microcontroller/BOTTON_2: J5.3, R20.2, SW4.1; also elsewhere on the board
/Microcontroller/BUZZER_1: J5.9, Q3.1 (B); also elsewhere on the board
/Microcontroller/I2C0_SCL: J5.7; also elsewhere on the board
/Microcontroller/I2C0_SDA: J5.5; also elsewhere on the board
/Microcontroller/SD_CS: J5.2; also elsewhere on the board
/Microcontroller/SD_MISO: J5.6; also elsewhere on the board
/Microcontroller/SD_MOSI: J5.4; also elsewhere on the board
/Microcontroller/SD_SCK: J5.8; also elsewhere on the board
/Microcontroller/TFT_CS: J5.10; also elsewhere on the board
/Microcontroller/TFT_D/C: J5.14; also elsewhere on the board
/Microcontroller/TFT_LED: J5.20; also elsewhere on the board
/Microcontroller/TFT_MISO: J5.18; also elsewhere on the board
/Microcontroller/TFT_MOSI: J5.22; also elsewhere on the board
/Microcontroller/TFT_RESET: J5.12; also elsewhere on the board
/Microcontroller/TFT_SCK: J5.16; also elsewhere on the board
/Microcontroller/TOUCH_CLK: J5.24; also elsewhere on the board
/Microcontroller/TOUCH_CS: J5.26; also elsewhere on the board
/Microcontroller/TOUCH_IRQ: J5.32; also elsewhere on the board
/Microcontroller/TOUCH_MISO: J5.30; also elsewhere on the board
/Microcontroller/TOUCH_MOSI: J5.28; also elsewhere on the board
/Sensor/ACCEL_INT1: J5.21; also elsewhere on the board
/Sensor/ACCEL_INT2: J5.19; also elsewhere on the board
/Sensor/HEARTRATE_INT: J5.23; also elsewhere on the board
/Sensor/INT_DRDY: J5.17; also elsewhere on the board
/Sensor/LIGHT_INT: J5.15; also elsewhere on the board
GND: BZ1.1 (+), D8.3 (VSS), D9.3 (VSS), D11.3 (VSS), D12.3 (VSS), D13.3 (VSS), D14.3 (VSS), D16.3 (VSS), D17.3 (VSS), J5.29, J5.31, Q3.2 (E), SW3.2, SW4.2; also elsewhere on the board
unnamed: D8.2 (DOUT), D9.4 (DIN)
unnamed: D9.2 (DOUT), D10.4 (DIN)
unnamed: D10.2 (DOUT), D11.4 (DIN)
unnamed: D11.2 (DOUT), D12.4 (DIN)
unnamed: D12.2 (DOUT), D13.4 (DIN)
unnamed: D13.2 (DOUT), D14.4 (DIN)
unnamed: D14.2 (DOUT), D15.4 (DIN)
unnamed: D15.2 (DOUT), D16.4 (DIN)
unnamed: D16.2 (DOUT), D17.4 (DIN)

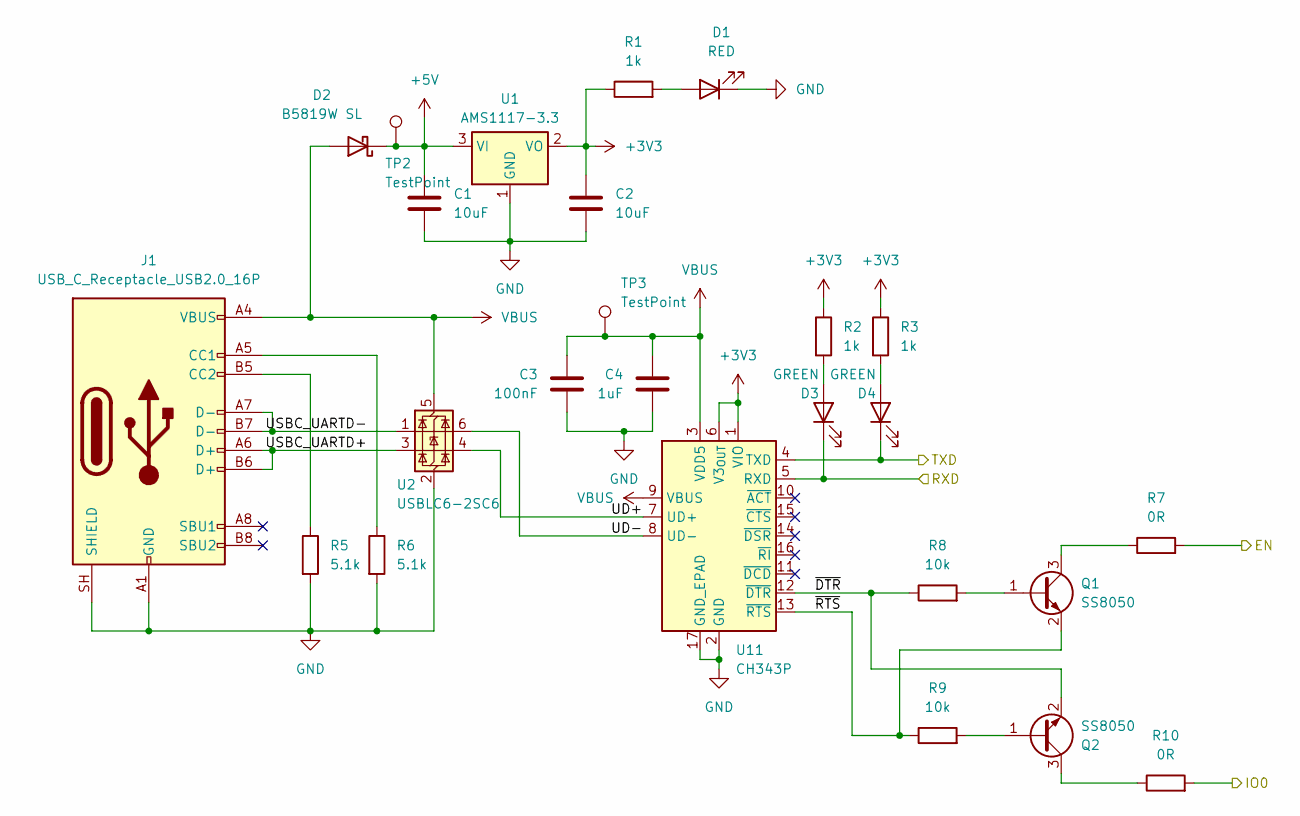
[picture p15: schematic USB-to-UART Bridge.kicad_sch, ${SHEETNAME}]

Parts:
C1, C2: 10uF; C_0603_1608Metric_Pad1.08x0.95mm_HandSolder; MPN CL10A106KP8NNNC
C3: 100nF; C_0402_1005Metric_Pad0.74x0.62mm_HandSolder; MPN CL05B104KO5NNNC
C4: 1uF; C_0603_1608Metric_Pad1.08x0.95mm_HandSolder; MPN CL10A105KB8NNNC
D1: RED; LED_0805_2012Metric_Pad1.15x1.40mm_HandSolder; MPN NCD0805R1
D2: B5819W SL; D_SOD-123; MPN B5819W SL
D3, D4: GREEN; LED_0805_2012Metric_Pad1.15x1.40mm_HandSolder; MPN KT-0805G
J1: USB_C_Receptacle_USB2.0_16P; USB_C_Receptacle_G-Switch_GT-USB-7010ASV; MPN G-Switch GT-USB-7010ASV
Q1, Q2: SS8050; SOT-23; MPN S8050 J3Y(RANGE:200-350)
R1, R2, R3: 1k; R_0603_1608Metric_Pad0.98x0.95mm_HandSolder; MPN 0603WAF1001T5E
R5, R6: 5.1k; R_0603_1608Metric_Pad0.98x0.95mm_HandSolder; MPN 0603WAF5101T5E
R7, R10: 0R; R_0603_1608Metric_Pad0.98x0.95mm_HandSolder; MPN 0603WAF0000T5E
R8, R9: 10k; R_0603_1608Metric_Pad0.98x0.95mm_HandSolder; MPN 0603WAF1002T5E
TP2, TP3: TestPoint; TestPoint_Pad_D1.5mm
U1: AMS1117-3.3; SOT-223-3_TabPin2; MPN AMS1117-3.3
U2: USBLC6-2SC6; SOT-23-6; MPN USBLC6-2SC6
U11: CH343P; WCH_QFN-16-1EP_3x3mm_P0.5mm_EP1.8x1.8mm; MPN CH343P

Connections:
+3V3: C2.1, R1.1, R2.1, R3.1, U1.2 (VO), U11.1 (VIO), U11.6 (V3_{OUT}); also elsewhere on the board
+5V: C1.1, D2.1 (K), TP2.1 (1_1), U1.3 (VI); also elsewhere on the board
/Microcontroller/BOOT: R10.2; also elsewhere on the board
/Microcontroller/EN: R7.2; also elsewhere on the board
/Microcontroller/RXD0: D4.1 (K), U11.4 (TXD); also elsewhere on the board
/Microcontroller/TXD0: D3.1 (K), U11.5 (RXD); also elsewhere on the board
/USB-to-UART Bridge/UD+: U2.4 (I/O2), U11.7 (UD+)
/USB-to-UART Bridge/UD-: U2.6 (I/O1), U11.8 (UD-)
/USB-to-UART Bridge/USBC_UARTD+: J1.A6 (D+), J1.B6 (D+), U2.3 (I/O2)
/USB-to-UART Bridge/USBC_UARTD-: J1.A7 (D-), J1.B7 (D-), U2.1 (I/O1)
/USB-to-UART Bridge/~DTR: Q2.2 (E), R8.1, U11.12 (~DTR)
/USB-to-UART Bridge/~RTS: Q1.2 (E), R9.1, U11.13 (~RTS)
GND: C1.2, C2.2, C3.2, C4.2, D1.1 (K), J1.A1 (GND), J1.A12 (GND), J1.B1 (GND), J1.B12 (GND), J1.SH (SHIELD), R5.2, R6.2, U1.1 (GND), U2.2 (GND), U11.2 (GND), U11.17 (GND_EPAD); also elsewhere on the board
unnamed: D1.2 (A), R1.2
unnamed: D3.2 (A), R2.2
unnamed: D4.2 (A), R3.2
unnamed: J1.A5 (CC1), R6.1
unnamed: J1.B5 (CC2), R5.1
unnamed: Q1.1 (B), R8.2
unnamed: Q1.3 (C), R7.1
unnamed: Q2.1 (B), R9.2
unnamed: Q2.3 (C), R10.1
VBUS: C3.1, C4.1, D2.2 (A), J1.A4 (VBUS), J1.A9 (VBUS), J1.B4 (VBUS), J1.B9 (VBUS), TP3.1 (1_1), U2.5 (VBUS), U11.3 (VDD5), U11.9 (VBUS)

Board: 2 copper layers, 111 parts (0 on the bottom side), 107 nets, no tracks yet.
